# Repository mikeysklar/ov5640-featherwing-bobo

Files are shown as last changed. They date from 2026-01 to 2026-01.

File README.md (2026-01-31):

# OV5640 FeatherWing BoBo  

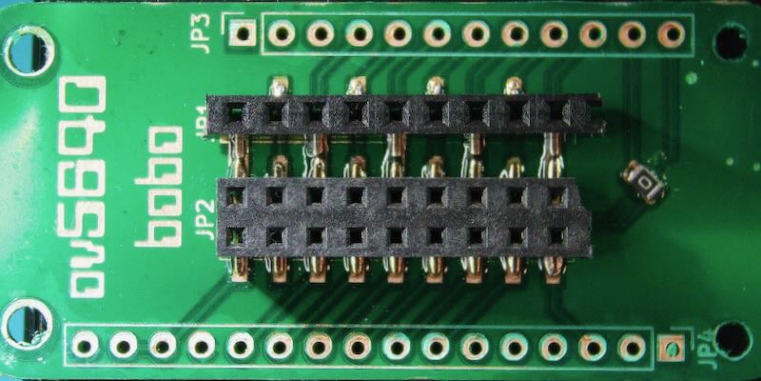
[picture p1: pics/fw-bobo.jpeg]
FeatherWing BoBo board


FeatherWing PCB that connects to the OV5640 camera breakout module from Adafruit 

---

## Overview

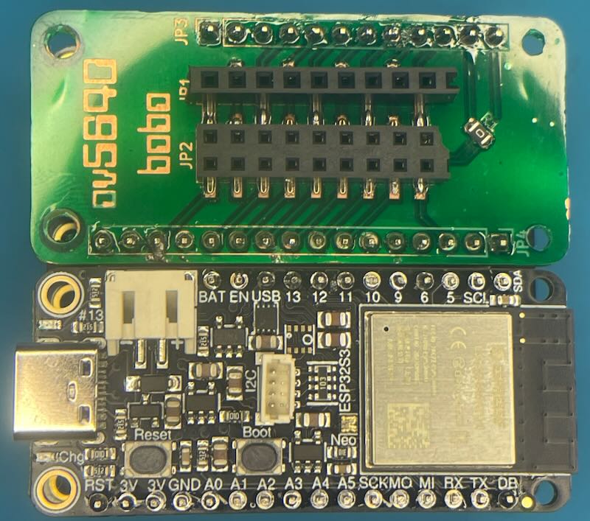
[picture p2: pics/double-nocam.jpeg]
Double board – no camera attached


- OV5640 camera breakout supports both header configurations
- Converts the OV5640 Breakout to a FeatherWing format
- Leaves SPI pins available for SD / SDIO use
- Third header row for breadboard-friendly layouts
- Single Sided PCB for easy rapid prototyping at home
- Compatible with **most Feather boards**
- Tested with **Feather ESP32-S3**

---

## BOM

| Item | Description |
|---|---|
| [Adafruit ESP32-S3 Feather with 4MB Flash 2MB PSRAM – STEMMA QT / Qwiic](https://www.adafruit.com/product/5477) | ESP32-S3 Feather board with 4 MB Flash, 2 MB PSRAM |
| [Adafruit OV5640 Camera Breakout – 120 Degree Lens with Autofocus](https://www.adafruit.com/product/5838) | OV5640 camera module, 120° lens, autofocus |
| [FeatherWing Doubler – Prototyping Add-on For All Feather Boards](https://www.adafruit.com/product/2890) | FeatherWing prototyping add-on board |
| [Single-row SMT headers](https://www.aliexpress.us/item/3256805008610566.html) | Surface-mount single-row pin headers |
| [Double-row SMT headers](https://www.aliexpress.us/item/3256803267239198.html) | Surface-mount double-row pin headers |

---

## Backstory

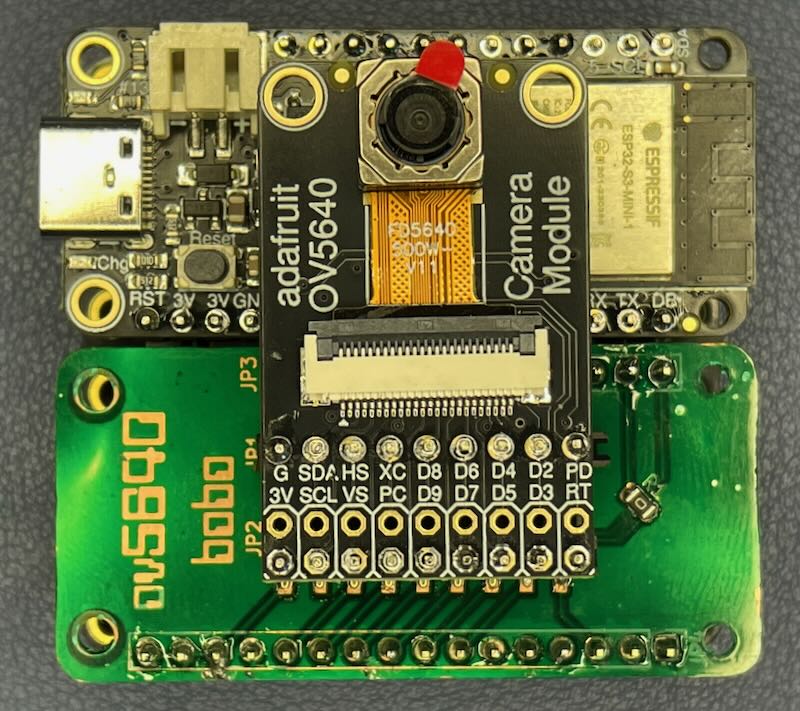
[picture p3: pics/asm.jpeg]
Assembly


**OV5640 FeatherWing BoBo** was created to solve a real-world wiring problem discussed 
on the forums [Adafruit forums](https://forums.adafruit.com/viewtopic.php?t=221951).

Special thanks to [Jerry Needell for his reference design and example code](https://github.com/jerryneedell/mycamera). 

---

## CircuitPython

- Tested on v10.0.3
- required libraries:
  - @jerryn [mycamera](https://github.com/jerryneedell/mycamera/tree/main) 
  - adafruit_requests 
  - adafruit_io

---

## Etching Settings

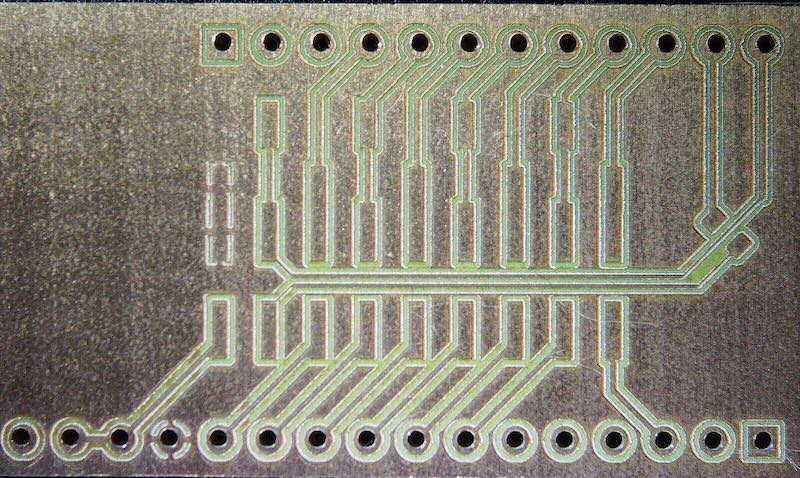
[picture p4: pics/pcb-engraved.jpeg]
Engraved PCB


---

## Stencil

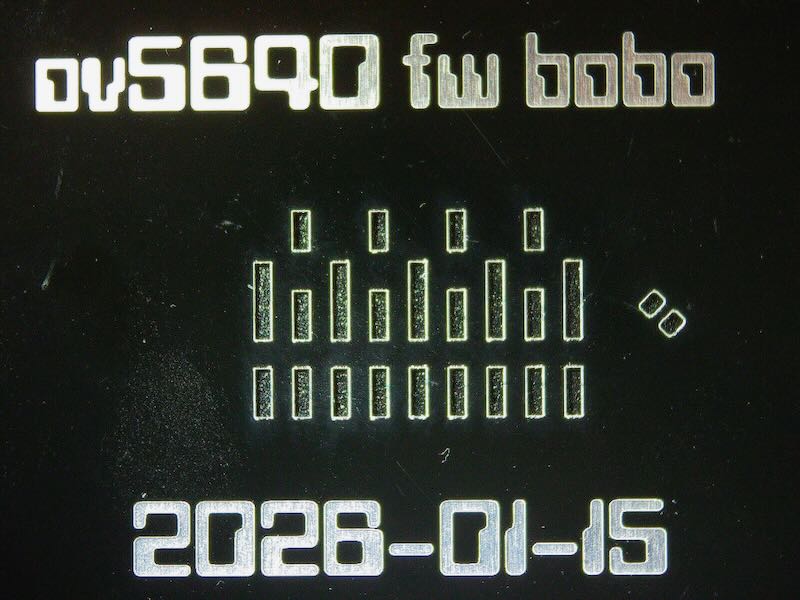
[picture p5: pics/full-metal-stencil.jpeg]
Full metal stencil


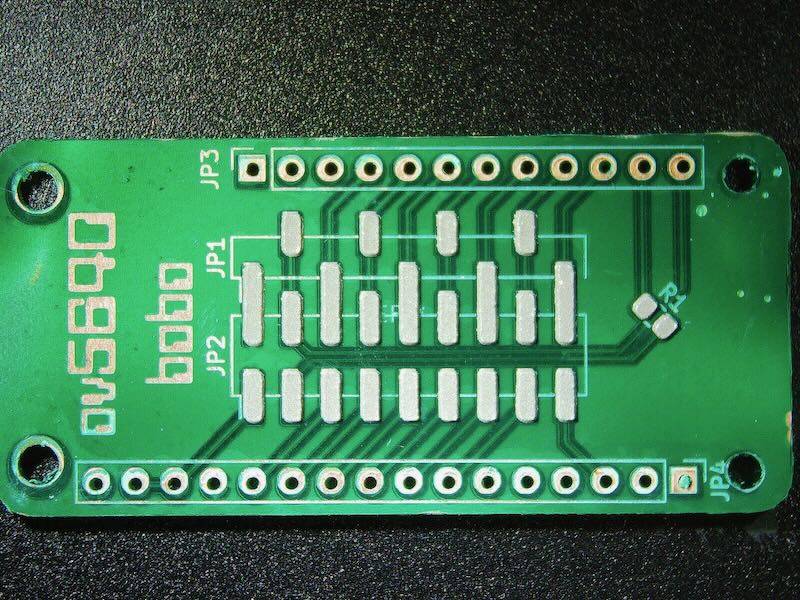
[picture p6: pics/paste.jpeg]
Solder paste applied


---

## Schematic
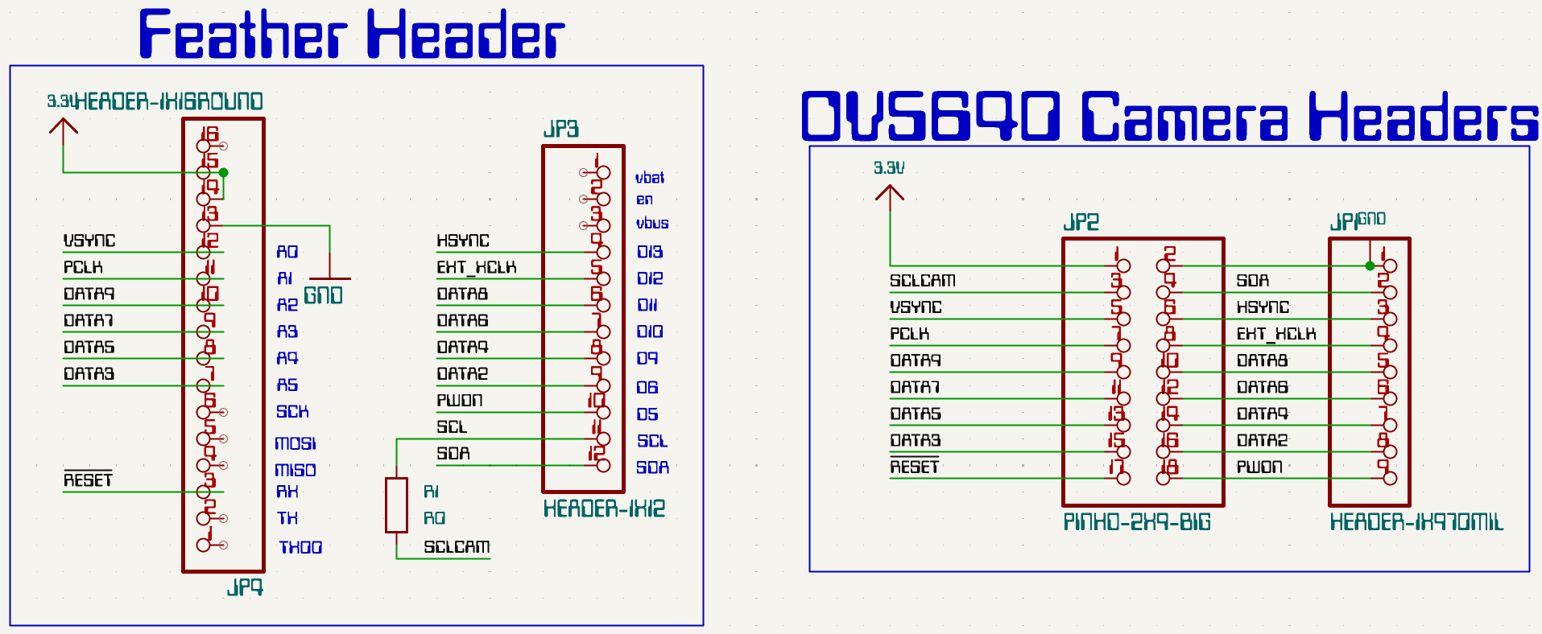
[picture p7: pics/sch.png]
Schematic


---

## PCB
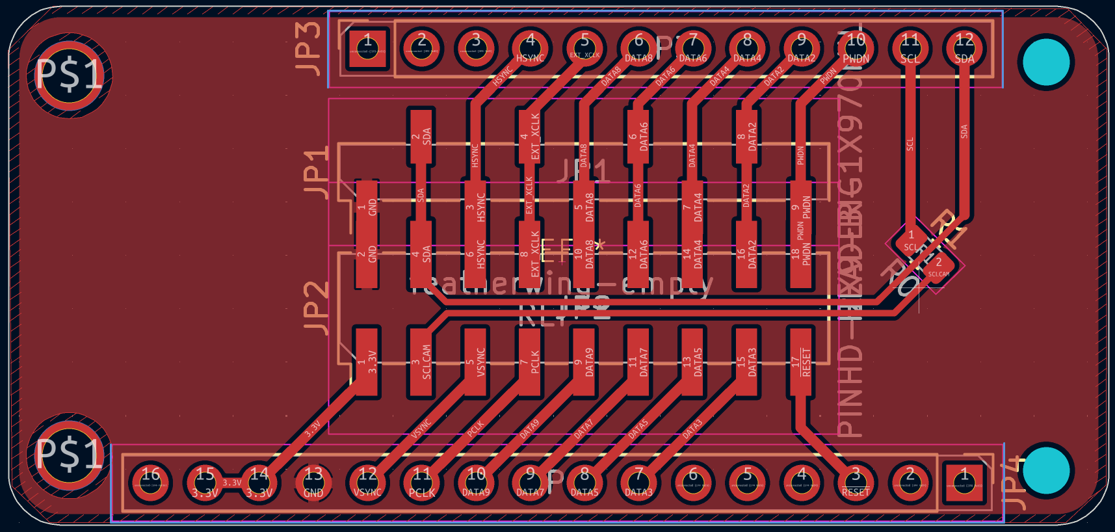
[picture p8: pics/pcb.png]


---

## KiCAD 3D
PCB tag detail

---

## Snapshot Test Code
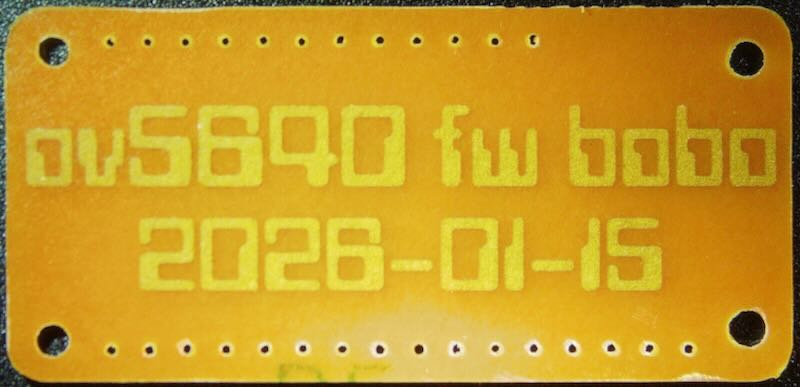
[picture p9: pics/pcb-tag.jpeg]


---

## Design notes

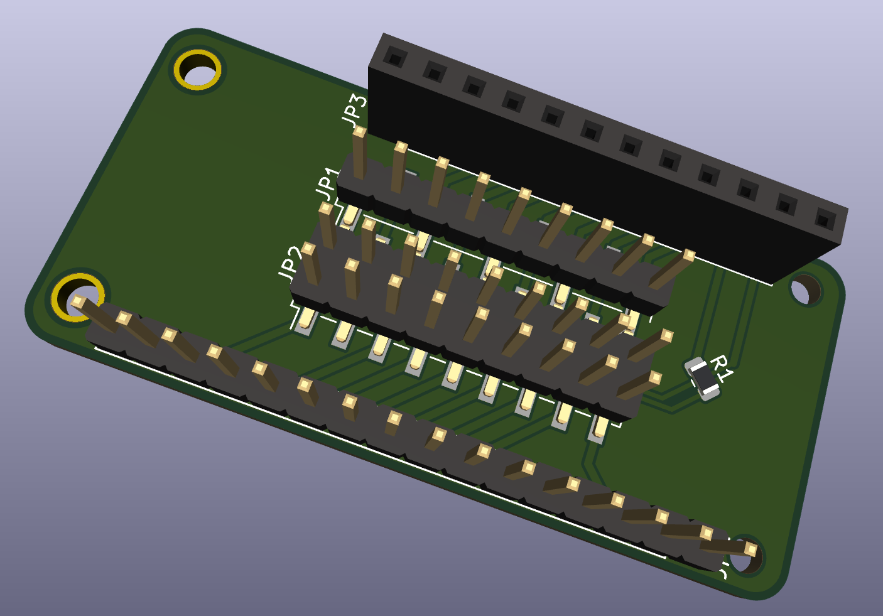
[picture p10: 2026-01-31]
pics/kicad-3d.png

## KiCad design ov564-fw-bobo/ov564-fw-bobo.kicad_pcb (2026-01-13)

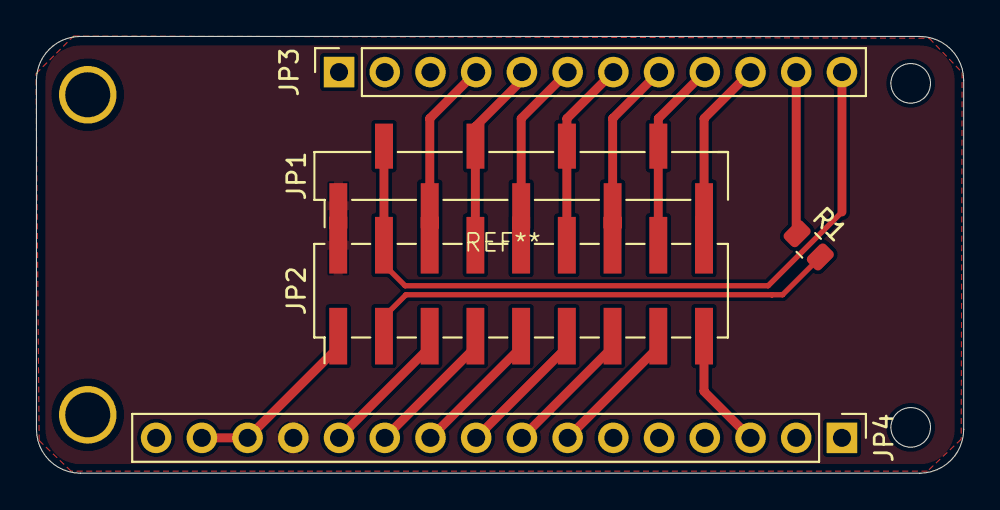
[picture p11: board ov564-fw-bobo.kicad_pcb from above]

Board: 2 copper layers, 51.5 x 24.3 mm, 5 parts (0 on the bottom side), 19 nets.

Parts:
JP1: HEADER-1X970MIL; PinHeader_1x09_P2.54mm_Vertical_SMD_Pin1Left
JP2: PINHD-2X9-BIG; PinHeader_2x09_P2.54mm_Vertical_SMD
JP3: HEADER-1X12; PinSocket_1x12_P2.54mm_Vertical
JP4: HEADER-1X16ROUND; PinHeader_1x16_P2.54mm_Vertical
R1: R0; R_0805_2012Metric

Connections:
3.3V: JP2.1, JP4.14, JP4.15
/DATA2: JP1.8, JP2.16, JP3.9
/DATA3: JP2.15, JP4.7
/DATA4: JP1.7, JP2.14, JP3.8
/DATA5: JP2.13, JP4.8
/DATA6: JP1.6, JP2.12, JP3.7
/DATA7: JP2.11, JP4.9
/DATA8: JP1.5, JP2.10, JP3.6
/DATA9: JP2.9, JP4.10
/EXT_XCLK: JP1.4, JP2.8, JP3.5
/HSYNC: JP1.3, JP2.6, JP3.4
/PCLK: JP2.7, JP4.11
/PWDN: JP1.9, JP2.18, JP3.10
/SCL: JP3.11, R1.1
/SCLCAM: JP2.3, R1.2
/SDA: JP1.2, JP2.4, JP3.12
/VSYNC: JP2.5, JP4.12
/~RESET: JP2.17, JP4.3
GND: JP1.1, JP2.2, JP4.13

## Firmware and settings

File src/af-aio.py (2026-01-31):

import os
import time
import ssl
import binascii
import mycamera
import wifi
import socketpool
import adafruit_requests
from adafruit_io.adafruit_io import IO_HTTP, AdafruitIO_RequestError

print("CircuitPython OV5640 Camera")

aio_username = os.getenv("ADAFRUIT_AIO_USERNAME")
aio_key = os.getenv("ADAFRUIT_AIO_KEY")

if not aio_username or not aio_key:
    raise RuntimeError("Missing Adafruit IO credentials")

print(f"Connecting to {os.getenv('CIRCUITPY_WIFI_SSID')}")
wifi.radio.connect(
    os.getenv("CIRCUITPY_WIFI_SSID"),
    os.getenv("CIRCUITPY_WIFI_PASSWORD"),
)
print("Connected")

pool = socketpool.SocketPool(wifi.radio)
requests = adafruit_requests.Session(pool, ssl.create_default_context())

io = IO_HTTP(aio_username, aio_key, requests)

try:
    feed_camera = io.get_feed("camera")
except AdafruitIO_RequestError:
    feed_camera = io.create_new_feed("camera")

pycam = mycamera.MyCamera()
pycam.resolution = 3
pycam.autofocus()
print("AF Status:", pycam.autofocus_status)

def capture_send_image():
    pycam.autofocus()
    jpeg = pycam.capture_into_jpeg()
    print("Captured image")
    if jpeg is None:
        print("JPEG capture failed")
        return
    encoded_data = binascii.b2a_base64(jpeg).strip().decode("ascii")
    io.send_data(feed_camera["key"], encoded_data)
    print("Sent image")

while True:
    capture_send_image()
    time.sleep(15)

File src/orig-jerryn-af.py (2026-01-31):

# SPDX-FileCopyrightText: 2023 Brent Rubell for Adafruit Industries
#
# An open-source IoT doorbell with the Adafruit MEMENTO camera and Adafruit IO
#
# SPDX-License-Identifier: Unlicense
import os
import time
import ssl
import binascii
import digitalio
import mycamera
import board
import wifi
import socketpool
import adafruit_requests
from adafruit_io.adafruit_io import IO_HTTP, AdafruitIO_RequestError

print("CircuitPython OV5650 Camera")

### WiFi ###
# Add settings.toml to your filesystem CIRCUITPY_WIFI_SSID and CIRCUITPY_WIFI_PASSWORD keys
# with your WiFi credentials. DO NOT share that file or commit it into Git or other
# source control.

# Set your Adafruit IO Username, Key and Port in settings.toml
# (visit io.adafruit.com if you need to create an account,
# or if you need your Adafruit IO key.)
aio_username = os.getenv("ADAFRUIT_AIO_USERNAME")
aio_key = os.getenv("ADAFRUIT_AIO_KEY")

print(f"Connecting to {os.getenv('CIRCUITPY_WIFI_SSID')}")
wifi.radio.connect(
    os.getenv("CIRCUITPY_WIFI_SSID"), os.getenv("CIRCUITPY_WIFI_PASSWORD")
)
print(f"Connected to {os.getenv('CIRCUITPY_WIFI_SSID')}!")

pool = socketpool.SocketPool(wifi.radio)
requests = adafruit_requests.Session(pool, ssl.create_default_context())

# Initialize an Adafruit IO HTTP API object
io = IO_HTTP(os.getenv("AIO_USERNAME"), os.getenv("AIO_KEY"), requests)

# Adafruit IO feed configuration
try:
    # Get the 'camera' feed from Adafruit IO
    feed_camera = io.get_feed("camera")
except AdafruitIO_RequestError:
    # If no 'camera' feed exists, create one 
    # it needs to be amnually created
    print("Create a feed named camera and turn off history")

# Initialize amera
pycam = mycamera.MyCamera()
pycam.resolution = 3
pycam.autofocus()
#print("AF Status: ",pycam.autofocus_status, pycam.autofocus_vcm_step)
print("AF Status: ",pycam.autofocus_status)
def capture_send_image():
    """Captures an image and send it to Adafruit IO."""
    # Force autofocus and capture a JPEG image
    pycam.autofocus()
    #print("AF Status: ",pycam.autofocus_status, pycam.autofocus_vcm_step)
    #pycam.autofocus_vcm_step=255
    #print("AF Status: ",pycam.autofocus_status, pycam.autofocus_vcm_step)
    jpeg = pycam.capture_into_jpeg()
    print("Captured image!")
    if jpeg is not None:
        # Encode JPEG data into base64 for sending to Adafruit IO
        print("Encoding image...")
        encoded_data = binascii.b2a_base64(jpeg).strip()
        # Send encoded_data to Adafruit IO camera feed
        print("Sending image to Adafruit IO...")
        io.send_data(feed_camera["key"], encoded_data)
        print("Sent image to IO!")
    else:
        print("ERROR: JPEG frame capture failed!")
    print("DONE, waiting for next capture")


while True:
    capture_send_image()
    time.sleep(15)

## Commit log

2026-01-10 init sch done
    [ov564-fw-bobo.kicad_pcb, ov564-fw-bobo.kicad_sch]
2026-01-13 increased FW size, added resistor jump
    [ov564-fw-bobo.kicad_pcb]
2026-01-22 bom addded
